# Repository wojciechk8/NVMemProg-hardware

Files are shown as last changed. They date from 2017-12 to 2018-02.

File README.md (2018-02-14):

# NVMemProg — Non-Volatile Memory Programmer

This design is an universal memory programmer with USB 2.0 (high-speed mode) interface
to a host PC, 48 independent universal pin drivers, 2 power lines (VCC, VPP) and an ability
to generate arbitrary digital waveforms with the maximum speed of 24MHz.

**WARNING!**
There are missing components on the pcb, due to a mistake, which was
corrected only in the schematics. See TODO for more information.

## Design Description
Block diagram
<sub>Page numbers in upper left corners refer to schematics.</sub>

### MCU
FX2LP microcontroller from Cypress is used for USB communication.
It consists of enhanced 8051 CPU, 16kB RAM, GPIF and a few peripherals.

The GPIF interface can generate preprogrammed digital waveforms and allows
data to flow from USB buffers to the output without passing through the slow CPU.
The interface is clocked with max. speed of 48MHz, but the actual data rate is limited
by propagation delay in the FPGA, pin driver capacitance and a memory device itself.

The MCU firmware implements memory interface protocol and programming algorithm.
Host PC just sends or reads data from a USB endpoint and the MCU is responsible of
carrying out memory device communication.
Since the MCU doesn't have any non-volatile memory, all the data (firmware) is stored
in the RAM, which can be loaded with a firmware via USB.
For more information see the [firmware repository](https://github.com/wojciechk8/NVMemProg-firmware).

The I2C bus is used to control voltages and currents in the power supply unit.
There is also an EEPROM on the driver board to identify currently installed module
(for a possible subsequent pin driver modules). Another I2C EEPROM on the main board
(not shown on the block diagram) is used to store USB VID/PID and DAC calibration data.

Internal CPU bus has an access to the FPGA's registers. These registers are seen by
the CPU as an external data memory. Their meaning are dependent on currently
loaded FPGA configuration (see FPGA section below), which is loaded
through one of the serial ports. The second serial port is used to configure
pin driver module.

### FPGA
In the design was used Altera Cyclone FPGA in 144-pin TQFP package.

The use of the FPGA has two main purposes:
* to arbitrarily switch signals between microcontroller and memory socket
* to convert microcontroller LVCMOS (3.3V) voltage level to voltage level required
  by a memory device in 1.5–3.3V range¹

Other than that, the FPGA could implement memory communication interface in case
the direct GPIF connection doesn't fit well (particularly for serial interfaces: SPI, I2C, etc.).

Configuration files were generated in Quartus II as *Raw Binary Files* (.rbf). A file
is sent to the MCU through USB and then, using serial port, to the FPGA.

Sources of modules, with their description, are located in fpga directory:
* [Universal](fpga/Universal) — transparent connection between GPIF and memory socket

<sub>¹ 5V CMOS logic isn't supported, but vast majority of 5V memory devices have TTL voltage levels,
which is compatible with 3.3V LVCMOS. There are also pull-up resistors in the pin driver that could
provide ca. 4V, satisfying 5V CMOS input level. Using pull-ups however implies lower speed rates.</sub>

### Pin Driver
Pin driver is used to provide power supply to memory devices. It consists of 48 independent
electronic switches controlled by SIPO shift registers. The switch can be configured in 4 states,
connecting to a memory pin one of the following lines:
* MEM_VPP
* MEM_VCC
* GND
* N/C (pin driven by FPGA)

Moreover, each switch has a configurable pull-up resistor.

Because of the FPGA pins protection, connecting high voltage (up to 16V) to a memory pin doesn't
cause FPGA I/O damage.

### Power Supply
Power block diagram
<sub>Page numbers in upper left corners refer to schematics.</sub>

## EDA Tools
This project was designed using [gEDA suite](http://www.geda-project.org/). Library with symbols
and footprints used in the design is available [here](https://github.com/wojciechk8/geda-sym).
The library is also attached to this repository as a submodule (geda-sym). To get it contents
after cloning the repository run `git submodule update --init`.

Updating pcb after schematics change is done with `gsch2pcb [name].prj` inside main_board
or driver_board directory.

*The pcb layout in the next revision is going to be ported to* [pcb-rnd](http://repo.hu/projects/pcb-rnd/).

### Simulations
Some of the circuits were simulated using [ngspice](http://ngspice.sourceforge.net/).
Models of IO drivers were converted from IBIS to SPICE circuit using [darter](https://github.com/russdill/darter).
The simulations are located in sim directory.

## Firmware
Firmware for the microcontroller is available [here](https://github.com/wojciechk8/NVMemProg-firmware).

## Host PC Software
Host PC software is available [here](https://github.com/wojciechk8/NVMemProg-host).

## Benchmarks
TODO

## License
This design is licensed under CERN OHL v.1.2. See the LICENSE file for the full text of the license.

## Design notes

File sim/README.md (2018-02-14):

## Simulations
* io — I/O path of memory pins
* pwr — power supply circuits

To run a simulation use the script provided:  
```
./simulate [schematic].sch
```

*The simulations were tested with ngspice-26. The I/O simulations don't work with ngspice-27.*

## Calculations
The worksheet files contain calculations which were carrying out during design.

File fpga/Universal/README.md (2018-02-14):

This FPGA module allows switching MCU signals to an arbitrary memory pin without any processing.

Universal module block diagram

It consists of:
* 48 memory multiplexers (MEM_MUX)
* 16 GPIF data bus multiplexers (DATA_FX_MUX)
* 2 GPIF ready multiplexers (RDY_FX_MUX)

Each of the multiplexers has address input connected to a register. Data inputs of the registers
are connected to the MCU (8051 CPU) data bus. Register selection is controlled by Address Decoder
and Data Decoder which are connected to the MCU address bus. Output enable of the multiplexers
are controlled by data_dir signal, which is connected to CTL5 pin of GPIF.

MCU ports are connected with FPGA signals as shown:

Pin map

Register map of the module:

| Address | Register |
| --- | --- |
| 0x00–0x29  | MEM_MUX #0–#47 |
| 0x30–0x31  | RDY_FX_MUX #0–#1 |

MEM_MUX register:

| Value | Selected signal  |
| --- | --- |
| 0x00–0x1F¹ | Hi-Z |
| 0x20–0x2F  | data_fx\[0:15\]² |
| 0x30–0x38  | addr_fx\[0:8\] |
| 0x39–0x3D  | ctl_fx\[0:4\] |
| 0x3E | '0' |
| 0x3F | '1' |

<sub>¹ Bit 5 controls OE signal of the output buffer.</sub>  
<sub>² By selecting data_fx in the MEM_MUX, corresponding mem_pin signal is simultaneously selected
in DATA_FX_MUX. data_fx signals are therefore connecting in both directions automatically.</sub>

RDY_FX_MUX register:

| Value | Selected signal  |
| --- | --- |
| 0x00–0x29  | mem_pin\[0:47\]  |

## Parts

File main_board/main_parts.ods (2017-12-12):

device | value | footprint | quantity | refdes
CAPACITOR | 0 | 603 | 2 | C23 C33
CAPACITOR | 15p | 402 | 48 | C401 C402 C405 C406 C409 C410 C413 C414 C417 C418 C421 C422 C425 C426 C429 C430 C433 C434 C437 C438 C441 C442 C445 C446 C501 C502 C505 C506 C509 C510 C513 C514 C517 C518 C521 C522 C525 C526 C529 C530 C533 C534 C537 C538 C541 C542 C545 C546
CAPACITOR | 22p | 603 | 2 | C202 C203
CAPACITOR | 10n | 603 | 8 | C1 C61 C62 C64 C65 C67 C68 C81
CAPACITOR | 100n | 402 | 24 | C205 C206 C207 C208 C209 C210 C211 C212 C213 C215 C216 C301 C302 C304 C305 C306 C307 C308 C309 C310 C311 C312 C313 C314
CAPACITOR | 100n | 603 | 12 | C2 C3 C5 C36 C51 C63 C69 C83 C102 C204 C217 C218
CAPACITOR | 220n | 603 | 1 | C66
CAPACITOR | 1u | 603 | 6 | C37 C38 C82 C84 C85 C201
CAPACITOR | 10u | 805 | 3 | C52 C101 C219
CAPACITOR | 2n2 | 402 | 4 | C403 C404 C407 C408
CAPACITOR | 2n2 | 402 | 44 | C411 C412 C415 C416 C419 C420 C423 C424 C427 C428 C431 C432 C435 C436 C439 C440 C443 C444 C447 C448 C503 C504 C507 C508 C511 C512 C515 C516 C519 C520 C523 C524 C527 C528 C531 C532 C535 C536 C539 C540 C543 C544 C547 C548
CAPACITOR | 4u7 | 603 | 2 | C214 C303
CAPACITOR | 4u7 | 805 | 1 | C4
CAPACITOR | 680p | 603 | 2 | C22 C32
CAPACITOR | EEEFK1V101XP | NICHICON_WT_CAP_6p3_5p4 | 3 | C21 C26 C31
CAPACITOR | UCD1E471MNL1GS | NICHICON_WT_CAP_10_10 | 2 | C25 C35
CONNECTOR | 2411 02 | USB_2411 | 1 | J2
CONNECTOR | CONN14 | JUMPER14 | 4 | J601 J602 J603 J604
CONNECTOR | CONN2 | JUMPER2 | 2 | J201 J202
CONNECTOR | CONN3 | JUMPER3 | 1 | J203
CONNECTOR | CONN4X2 | HEADER8_2 | 2 | J605 J606
CONNECTOR | CONN5X2 | IDC_10 | 1 | J301
CONNECTOR | DC-10LP | DC_JACK_FC681465P | 1 | J1
CRYSTAL | 24MHz/16pF | HC49SM | 1 | X201
DIODE | BAS16 | SOT23 | 2 | D21 D31
DIODE | BAS40-06 | SOT23 | 24 | D402 D404 D406 D408 D410 D412 D414 D416 D418 D420 D422 D424 D502 D504 D506 D508 D510 D512 D514 D516 D518 D520 D522 D524
DIODE | BAV70 | SOT23 | 24 | D401 D403 D405 D407 D409 D411 D413 D415 D417 D419 D421 D423 D501 D503 D505 D507 D509 D511 D513 D515 D517 D519 D521 D523
DIODE | RB521S30 | SOD523 | 1 | D201
DIODE | SK14 | DO214AC | 2 | D22 D32
FERRITE BEAD | 600R | 603 | 3 | FB101 FB201 FB301
FERRITE BEAD | 600R | 805 | 1 | FB1
FUSE | PTC 1.5A | 1812 | 1 | F1
IC | 74HC74 | SO14 | 1 | U63
IC | APE8865 | SOT23_5 | 1 | U82
IC | CD4504 | SO16 | 1 | U203
IC | CY7C68013A-128 | TQFP128_R | 1 | U201
IC | EP1C3T144 | LQFP144_20 | 1 | U301
IC | LD1117S33C | SOT223 | 1 | U51
IC | LM317 | D2PAK-2 | 1 | U32
IC | LM393 | SO8 | 2 | U62 U81
IC | M24128 | SO8 | 1 | U202
IC | MC34063A | SO8 | 2 | U21 U31
IC | MCP4728 | MSOP10_A | 1 | U101
IC | TS912 | SO8 | 1 | U61
INDUCTOR | 100u/2.1A | FERROCORE_DE1207 | 2 | L21 L31
INDUCTOR | 1u | 1210 | 1 | L22
LED | GREEN | 805 | 1 | LED201
LED | RED | 805 | 1 | LED202
none | unknown | TP70 | 12 | TP1 TP2 TP21 TP31 TP32 TP51 TP61 TP62 TP81 TP82 TP201 TP202
RESISTOR | 0 | 603 | 10 | R101 R102 R103 R106 R107 R108 R109 R204 R205 R206
RESISTOR | 0R18 | 1206 | 2 | R61 R71
RESISTOR | 0R18/0.5W | 1206 | 2 | R22 R32
RESISTOR | 15 | 402 | 50 | R207 R208 R401 R404 R405 R408 R409 R412 R413 R416 R417 R420 R421 R424 R425 R428 R429 R432 R433 R436 R437 R440 R441 R444 R445 R448 R501 R504 R505 R508 R509 R512 R513 R516 R517 R520 R521 R524 R525 R528 R529 R532 R533 R536 R537 R540 R541 R544 R545 R548
RESISTOR | 10k | 402 | 3 | R209 R210 R213
RESISTOR | 10k | 603 | 1 | R66
RESISTOR | 10k | CTS_742C_08 | 2 | RP301 RP302
RESISTOR | 33k | 603 | 1 | R201
RESISTOR | 39k | 603 | 2 | R73 R75
RESISTOR | 100k | 603 | 2 | R2 R83
RESISTOR | 100k | 603 | 2 | R104 R105
RESISTOR | 11k 1% | 603 | 1 | R33
RESISTOR | 1k2 | 603 | 8 | R26 R36 R62 R64 R72 R74 R78 R211
RESISTOR | 1k2 | 805 | 1 | R38
RESISTOR | 1k2 1% | 603 | 1 | R39
RESISTOR | 220 | 805 | 4 | R5 R6 R84 R85
RESISTOR | 10k | 603 | 1 | R1
RESISTOR | 22k | 603 | 1 | R77
RESISTOR | 22k 1% | 603 | 2 | R24 R34
RESISTOR | 2k2 | 603 | 48 | R402 R403 R406 R407 R410 R411 R414 R415 R418 R419 R422 R423 R426 R427 R430 R431 R434 R435 R438 R439 R442 R443 R446 R447 R502 R503 R506 R507 R510 R511 R514 R515 R518 R519 R522 R523 R526 R527 R530 R531 R534 R535 R538 R539 R542 R543 R546 R547
RESISTOR | 2k2 | 805 | 1 | R28
RESISTOR | 2k4 | 603 | 4 | R27 R37 R202 R203
RESISTOR | 2k4 1% | 603 | 2 | R25 R40
RESISTOR | 3k3 | 603 | 2 | R81 R82
RESISTOR | 3k9 1% | 603 | 1 | R35
RESISTOR | 47 | 603 | 2 | R21 R31
RESISTOR | 390 | 805 | 1 | R42
RESISTOR | 910 | 603 | 1 | R212
RESISTOR | 47k | 603 | 3 | R3 R67 R69
RESISTOR | 75k | 603 | 2 | R63 R65
RESISTOR | 100k | 603 | 2 | R4 R68
RESISTOR | 5k6 | 603 | 2 | R70 R76
RESISTOR | 5k6 1% | 603 | 1 | R23
RESISTOR | 910 1% | 603 | 1 | R41
TRANSISTOR | BC807 | SOT23 | 2 | Q21 Q31
TRANSISTOR | BC847 | SOT23 | 3 | Q1 Q62 Q65
TRANSISTOR | DMP2305U | SOT23 | 2 | Q2 Q82
TRANSISTOR | IRF7420 | SO8 | 1 | Q64
TRANSISTOR | IRLML6344 | SOT23 | 3 | Q22 Q32 Q81
TRANSISTOR | IRLML9301 | SOT23 | 1 | Q61
TRANSISTOR | PDTC114ET | SOT23 | 2 | Q63 Q66
TVS | SMAJ5.0A | DO214AC | 1 | TVS2
TVS | USBLC6 | SOT23_6 | 1 | TVS1

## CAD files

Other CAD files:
fpga/Universal/stp2.stp
fpga/Universal/stp_data_dir.stp

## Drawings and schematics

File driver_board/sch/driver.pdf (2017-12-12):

A

B

C

D

1 | 2 | 3 | 4 | 5 | 6

A

B

C

D

# NVMemProg

# Non-Volatile Memory Programmer

2017-07-11

# Copyright © 2017 Wojciech Krutnik <wojciechk8@gmail.com>

# Driver Board Schematics

# rev. 0.1

# This documentation describes Open Hardware and is licensed under the

CERN OHL v. 1.2.

You may redistribute and modify this documentation under the terms of the CERN OHL v.1.2. (http://ohwr.org/cernohl). This documentation is distributed WITHOUT ANY EXPRESS OR IMPLIED WARRANTY, INCLUDING OF MERCHANTABILITY, SATISFACTORY QUALITY AND FITNESS FOR A PARTICULAR PURPOSE. Please see the CERN OHL v.1.2 for applicable conditions

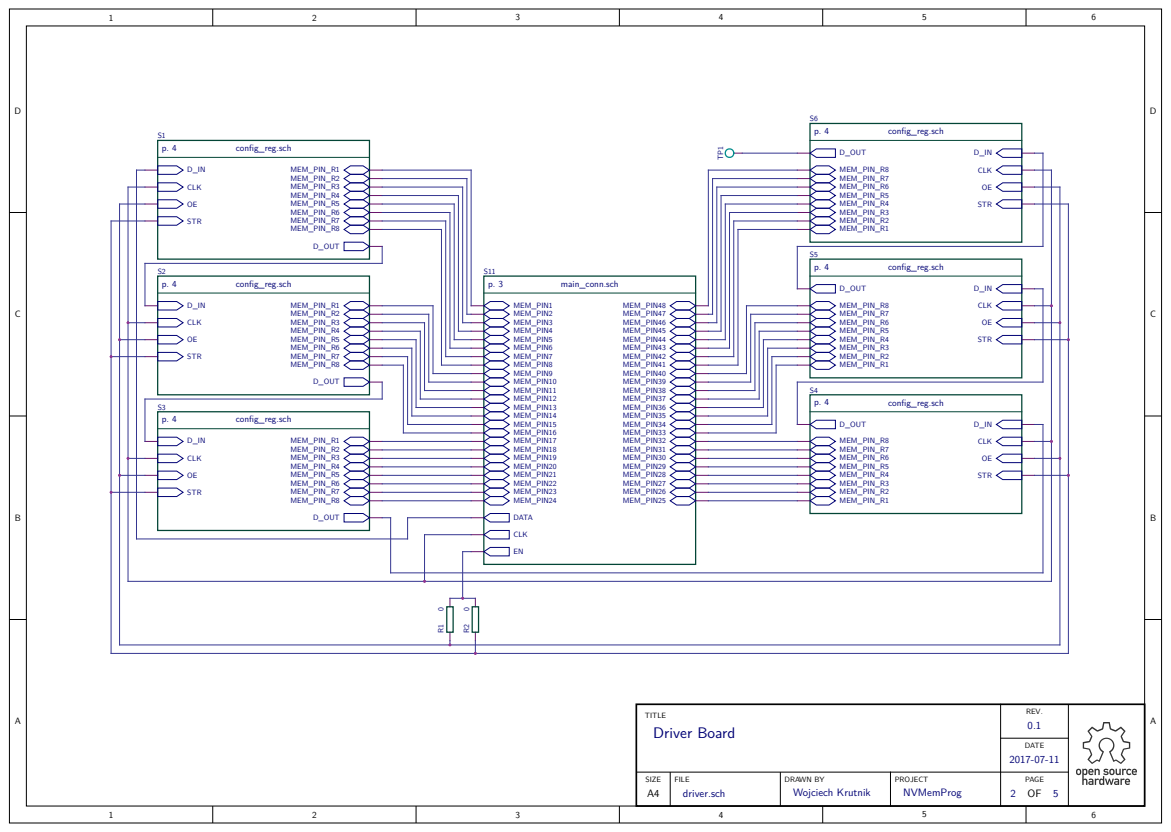
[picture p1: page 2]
FILE; REV.; DRAWN BY; PAGE; TITLE; PROJECT; DATE; SIZE A4; NVMemProg; Driver Board; driver.sch; Wojciech Krutnik; CLK; STR; D_OUT; MEM_PIN_R1 MEM_PIN_R2 MEM_PIN_R3 MEM_PIN_R4 MEM_PIN_R5 MEM_PIN_R6 MEM_PIN_R7 MEM_PIN_R8; config_reg.sch; DATA; MEM_PIN1; MEM_PIN10 MEM_PIN11 MEM_PIN12 MEM_PIN13 MEM_PIN14 MEM_PIN15 MEM_PIN16 MEM_PIN17 MEM_PIN18 MEM_PIN19; MEM_PIN2; MEM_PIN20 MEM_PIN21 MEM_PIN22 MEM_PIN23; MEM_PIN24; MEM_PIN25; MEM_PIN26; MEM_PIN27; MEM_PIN28; MEM_PIN29; MEM_PIN3; MEM_PIN30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

## VCCSCL

## BOARD ID ROM

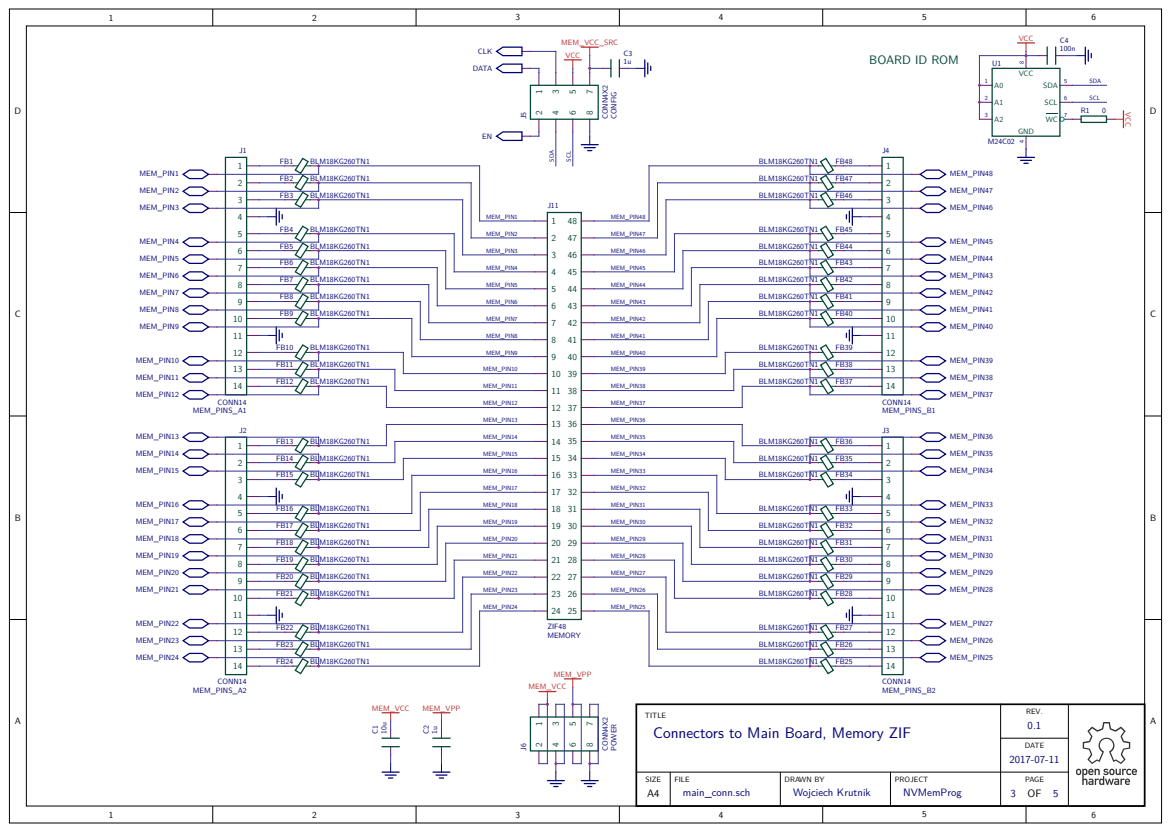
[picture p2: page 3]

TITLE
Connectors to Main Board, Memory ZIF

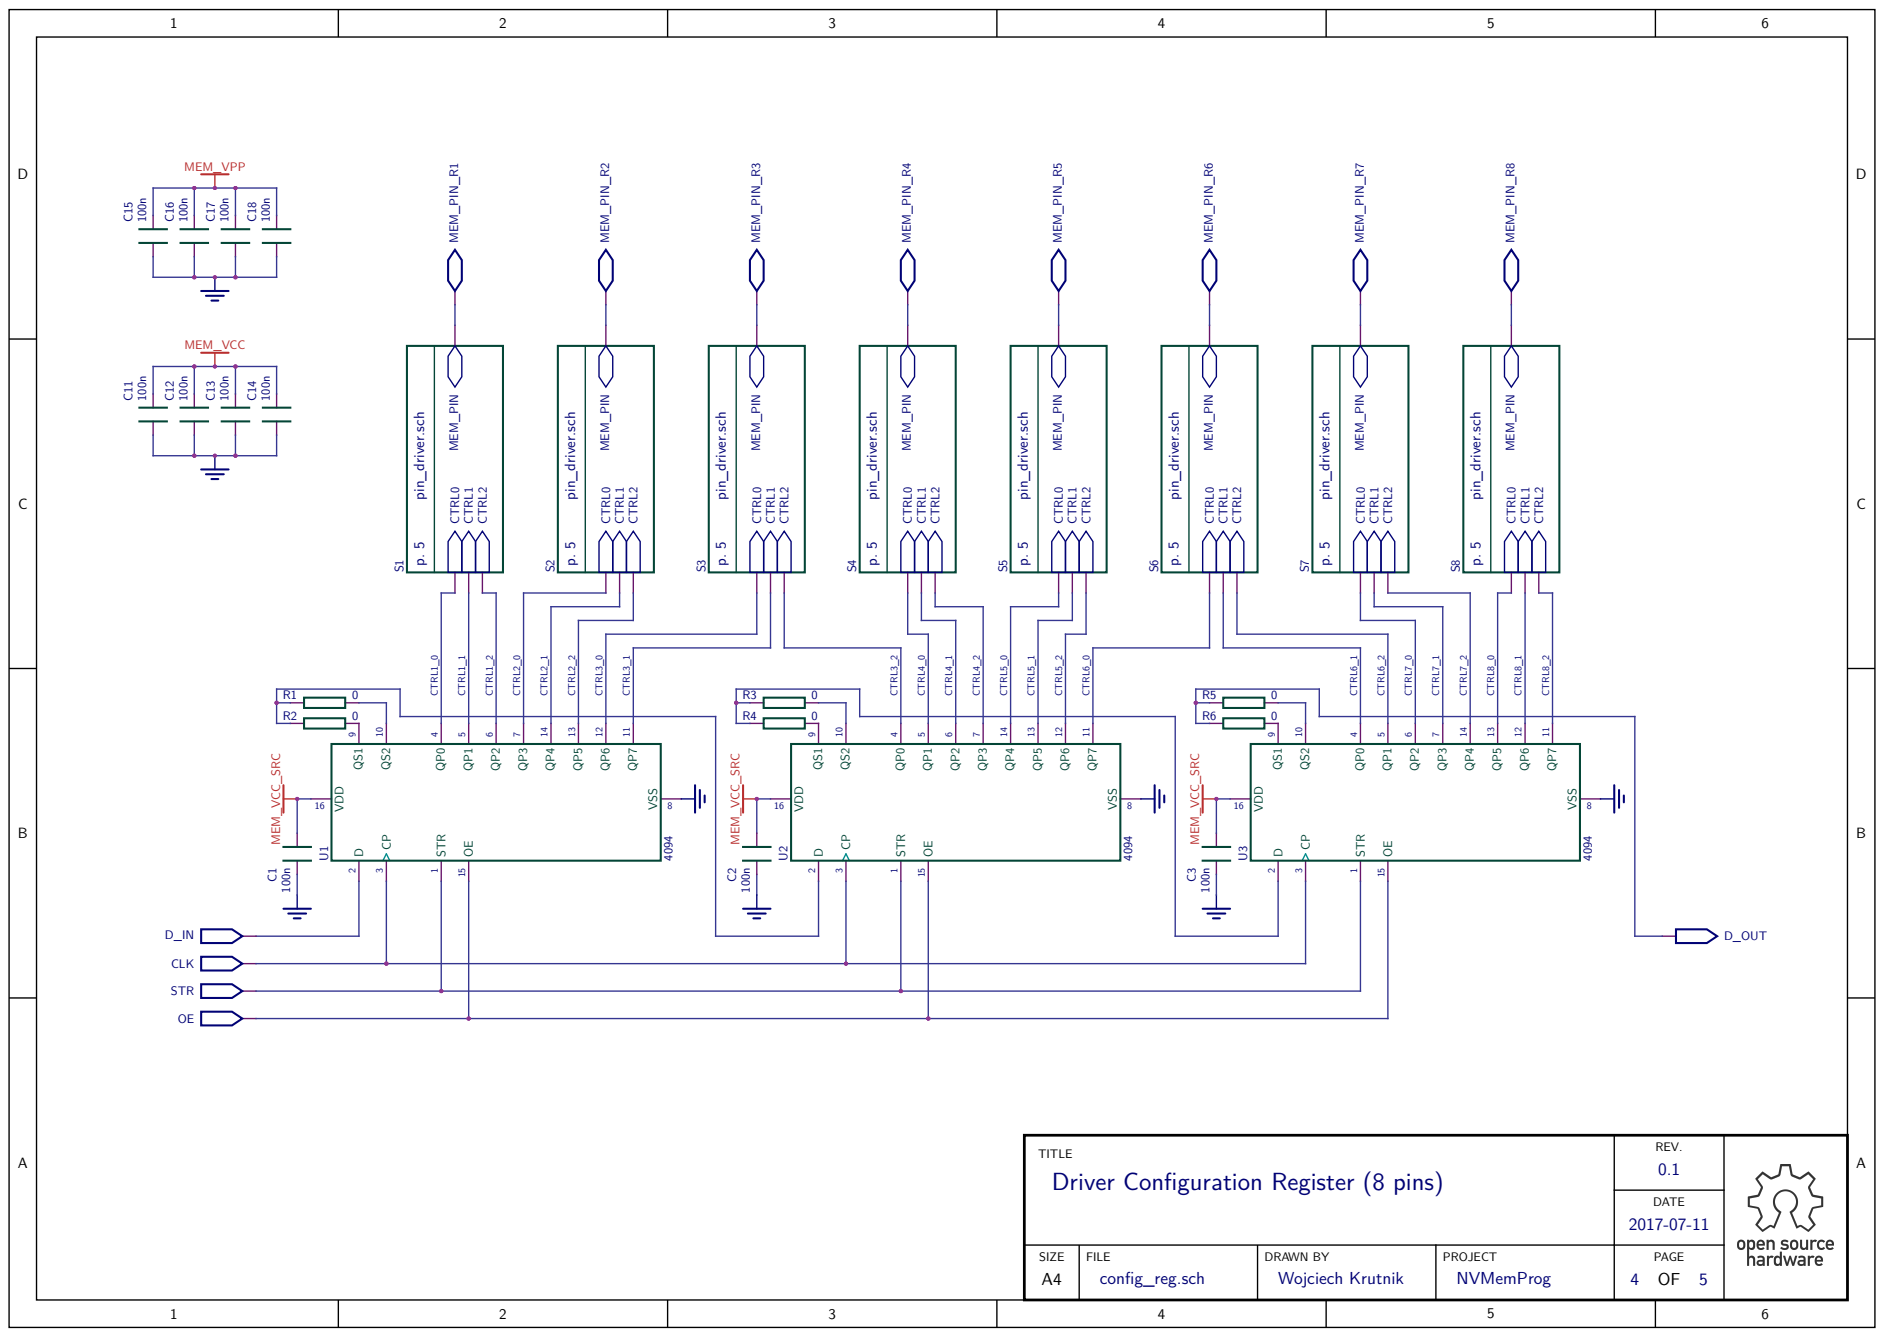
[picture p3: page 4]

TITLE
Driver Configuration Register (8 pins)

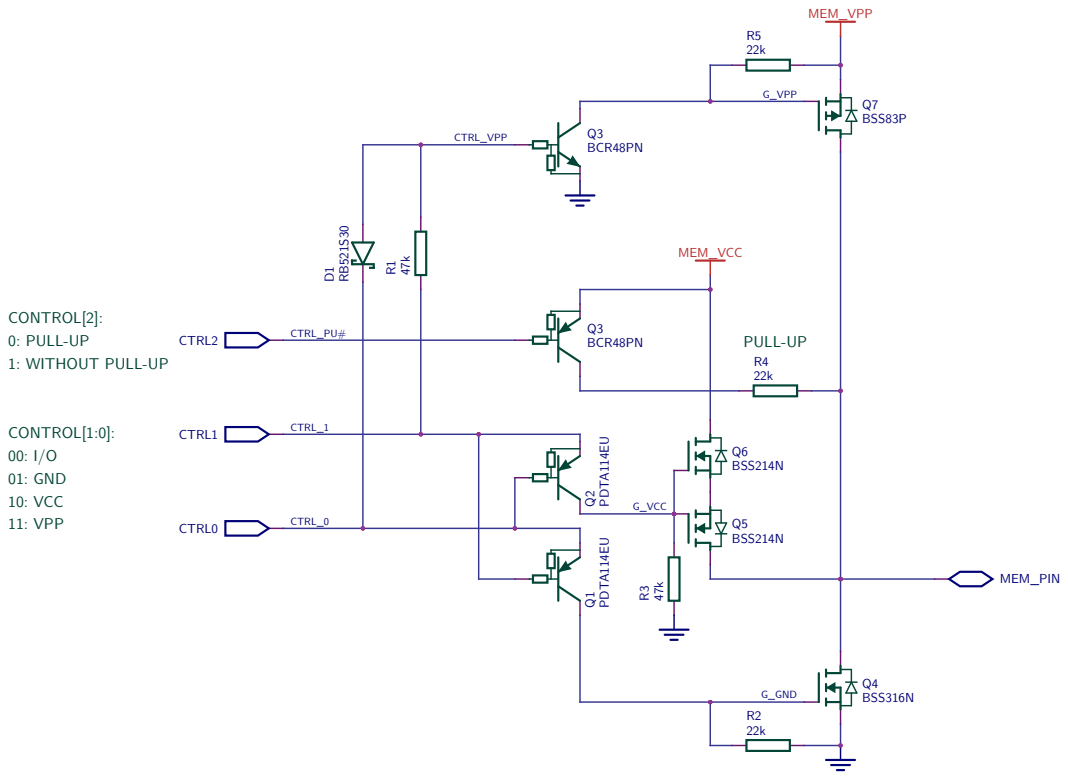
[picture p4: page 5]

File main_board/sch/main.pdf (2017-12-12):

A

B

C

D

1 | 2 | 3 | 4 | 5 | 6

A

B

C

D

# NVMemProg

# Non-Volatile Memory Programmer

2017-07-11

# Copyright © 2017 Wojciech Krutnik <wojciechk8@gmail.com>

# Main Board Schematics

# rev. 0.1

# This documentation describes Open Hardware and is licensed under the

CERN OHL v. 1.2.

You may redistribute and modify this documentation under the terms of the CERN OHL v.1.2. (http://ohwr.org/cernohl). This documentation is distributed WITHOUT ANY EXPRESS OR IMPLIED WARRANTY, INCLUDING OF MERCHANTABILITY, SATISFACTORY QUALITY AND FITNESS FOR A PARTICULAR PURPOSE. Please see the CERN OHL v.1.2 for applicable conditions

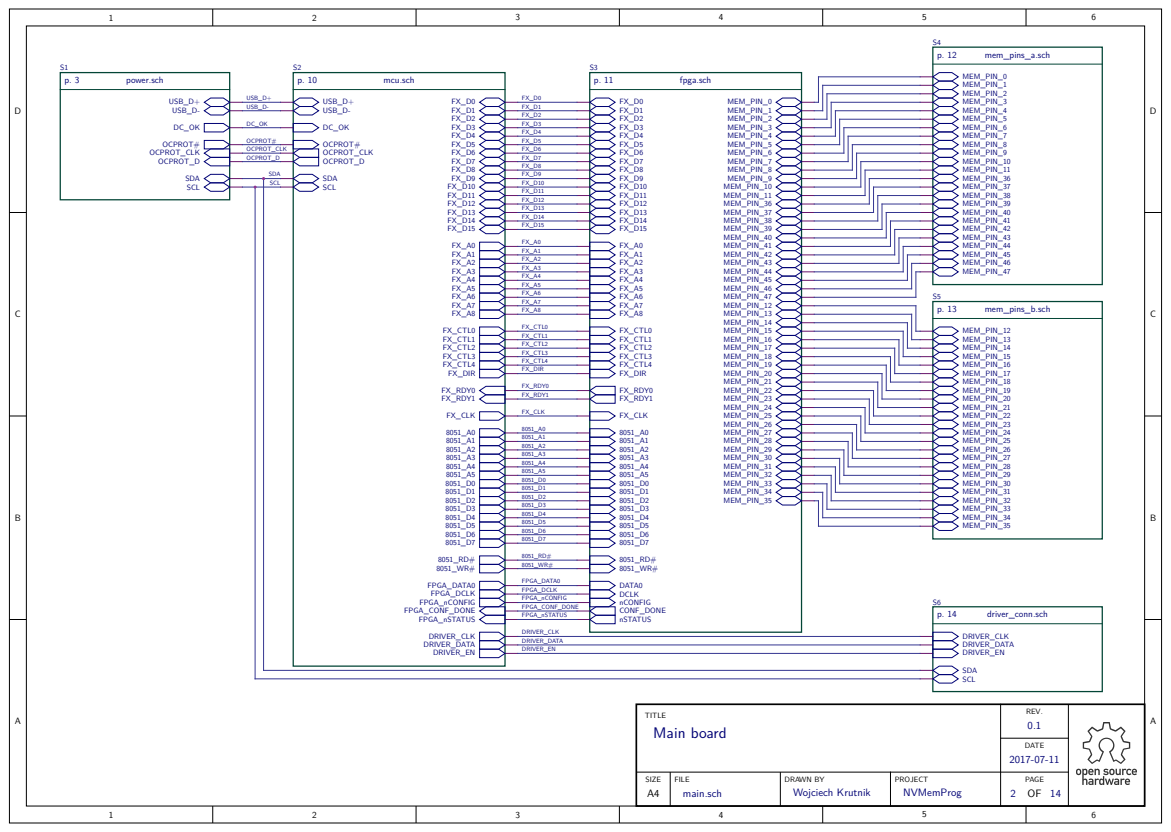
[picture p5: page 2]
ABCD; FILE; REV.; DRAWN BY; PAGE; TITLE; PROJECT; DATE; SIZE A4; NVMemProg; Main board; main.sch; Wojciech Krutnik; OCPROT_CLK OCPROT_D; OCPROT#; SCL; SDA; USB_D+ USB_D-; power.sch; FPGA_CONF_DONE FPGA_nSTATUS; FX_RDY0 FX_RDY1; DRIVER_CLK DRIVER_DATA DRIVER_EN; FPGA_DATA0 FPGA_DCLK FPGA_nCONFIG; FX_CLK; FX_CTL0 FX_CTL1 FX_CTL2 FX_CTL3 FX_CTL4 FX_DIR; mcu.sch; DATA0 DCLK; nCONFIG CONF_DONE; nSTATUS; MEM_PIN_0 MEM_PIN_1; MEM_PIN_10 MEM_PIN_11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

## [STEP-UP]

7~16V/0.25A

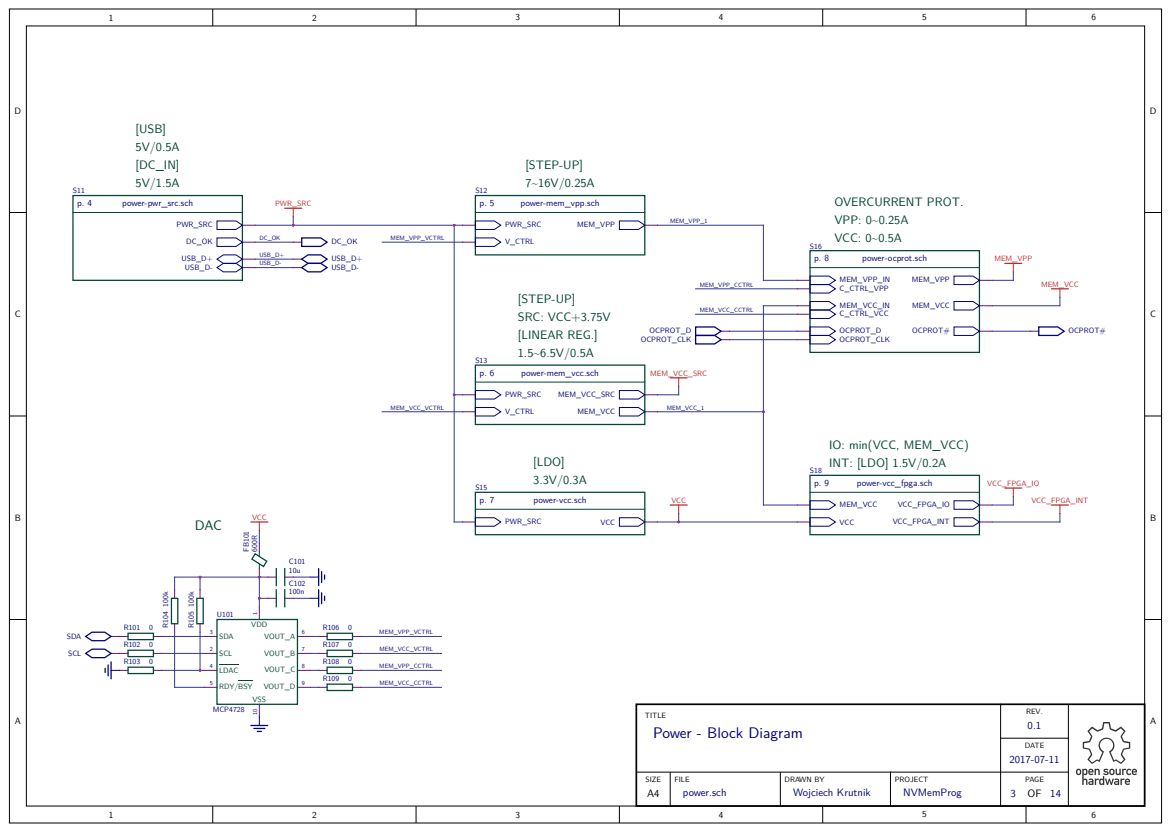
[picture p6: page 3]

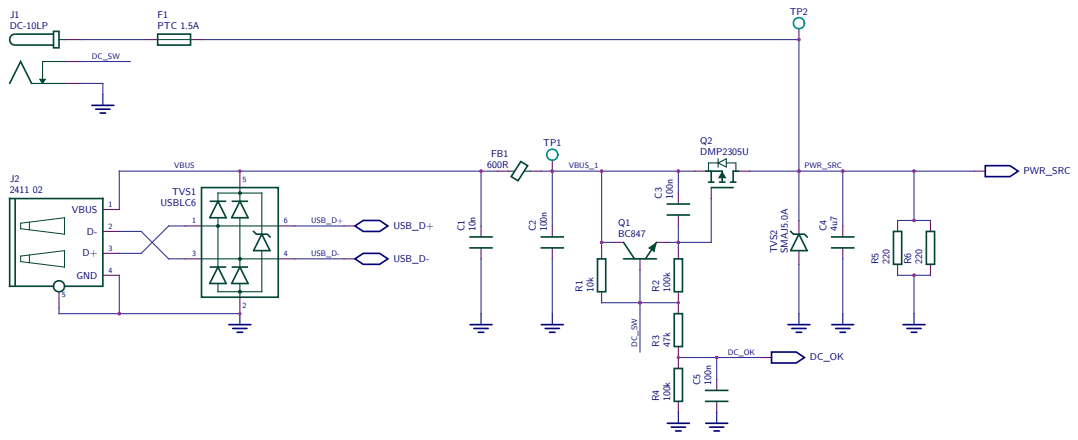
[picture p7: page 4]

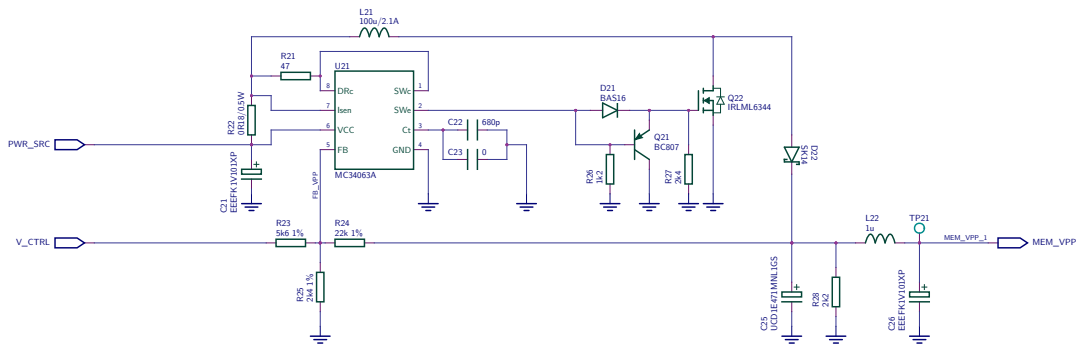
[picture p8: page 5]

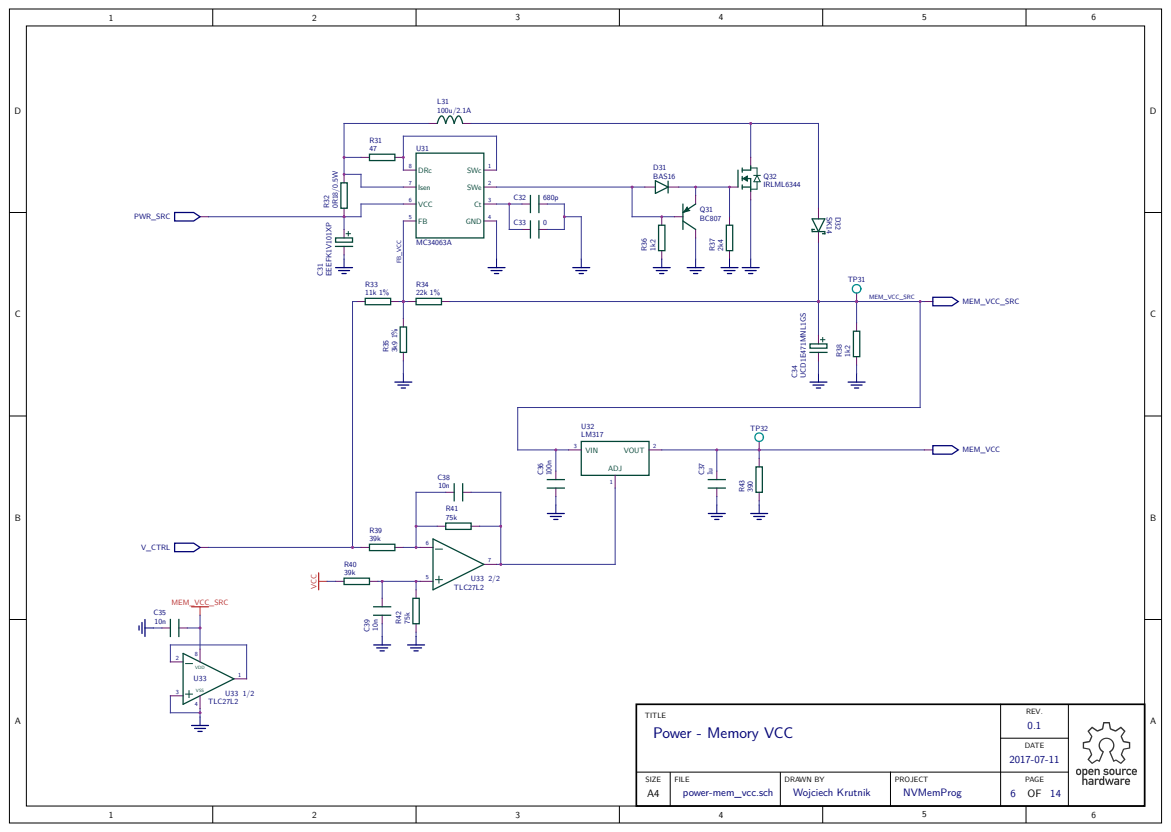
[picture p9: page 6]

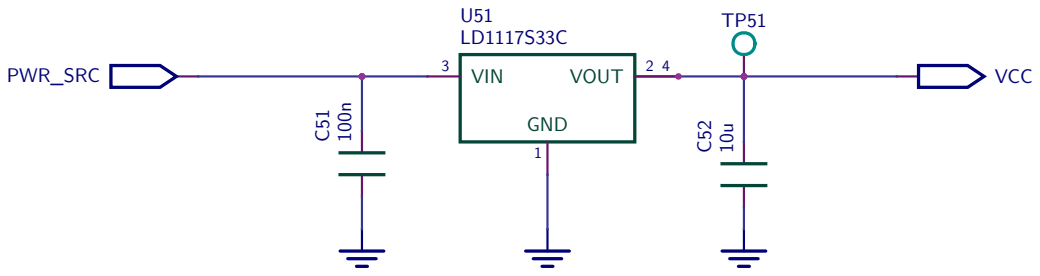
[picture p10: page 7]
FILE; REV.; DRAWN BY; PAGE; TITLE; PROJECT; DATE; SIZE; Power - VCC; power-vcc.sch; PWR_SRC; VIN; VCC ³; VOUT 2; GND 1

1.5V 6.6ms | 1.3ms | 7mA R⁷⁰ 5k6 R⁷⁸ 1k2

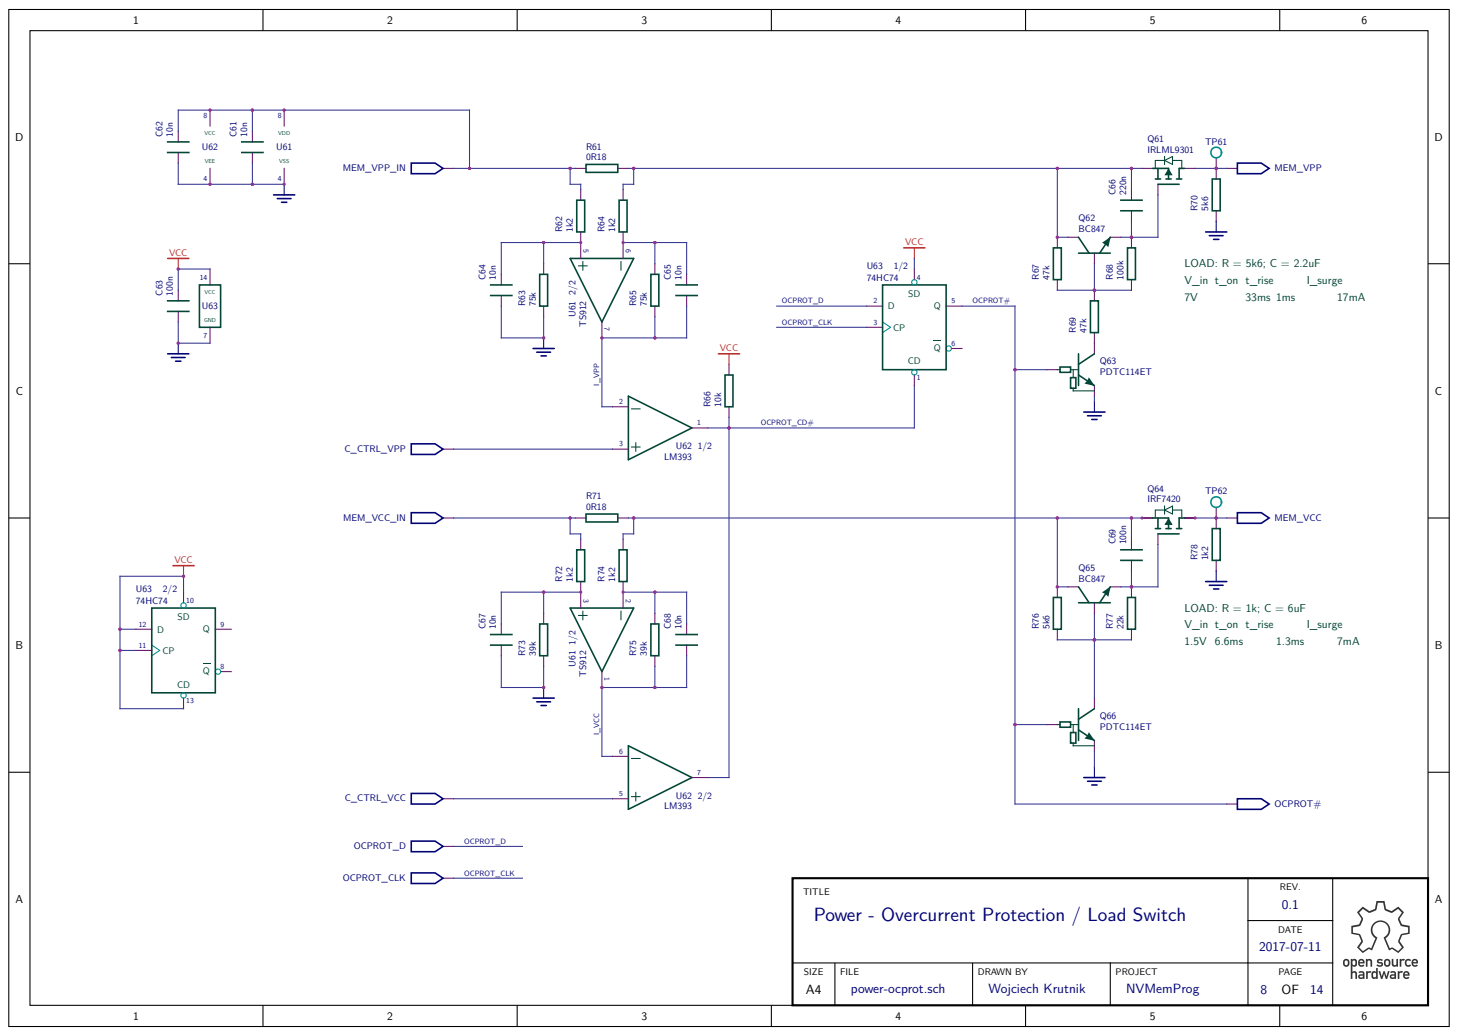
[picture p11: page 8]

TITLE
Power - Overcurrent Protection / Load Switch

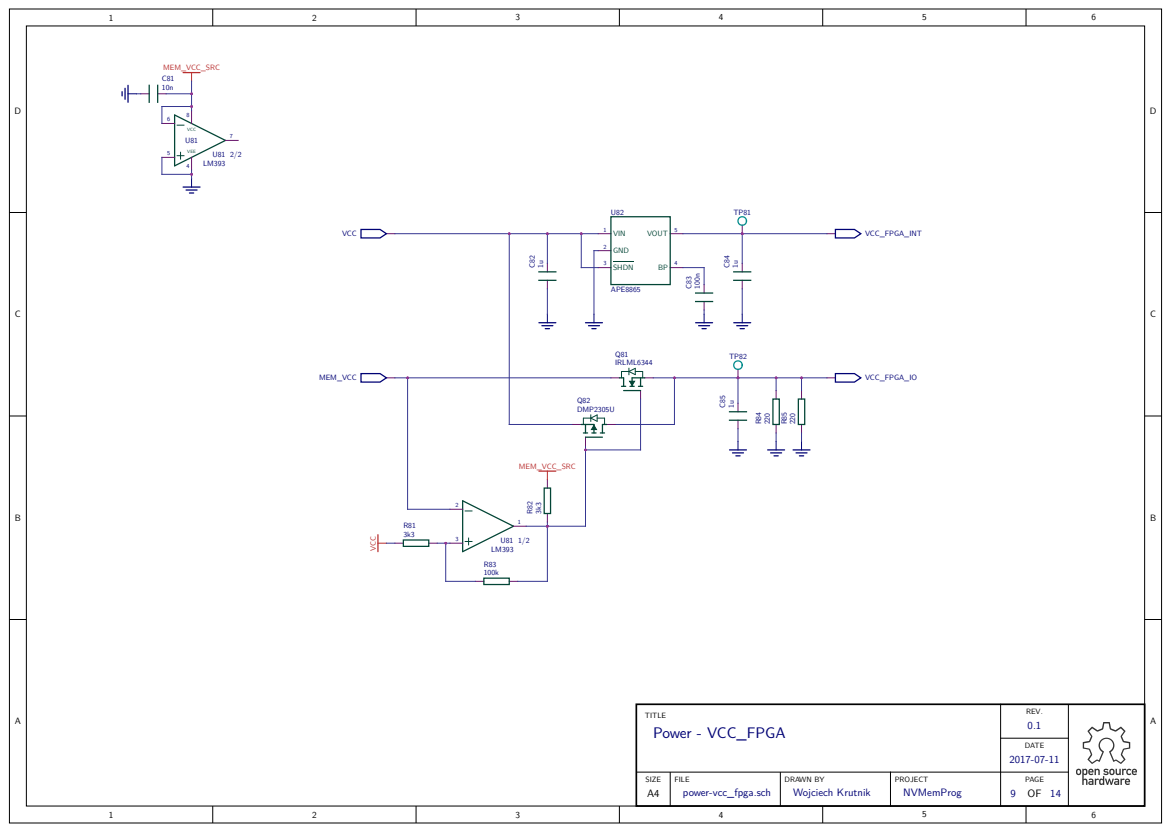
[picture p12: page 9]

# PC7/GPIFADR7 79 GND 80 VCC ⁸¹

# PA7/FLAGD/SLCS# 92 GND 93


DPLUS ¹⁸
DMINUS ¹⁹
RESET# ⁹⁹
WAKEUP ¹⁰¹
Reserved ³³
BKPT ³⁴
CLKOUT ¹
XTALOUT ¹¹ XTALIN ¹²

SCL ³⁶ SDA ³⁷

PSEN# ³⁹


## TO DRIVER BOARD


TITLE
FPGA Memory pins 1..24 protection, connector

## TO DRIVER BOARD


TITLE
FPGA Memory pins 25..48 protection, connector

FILE; REV.; DRAWN BY; PAGE; PROJECT; DATE; SIZE; driver_conn.sch; CONN4X2 POWER; CONN4X2 CONFIG; MEM_VCC; MEM_VCC_SRC; MEM_VPP; DRIVER_CLK; DRIVER_DATA; DRIVER_EN; SDA; SCL; VCC

TITLE
Connectors to Driver Board

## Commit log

2018-02-14 Add documentation
    [OCPROT.ods]
2018-02-14 Add TODO entry about power soft start
